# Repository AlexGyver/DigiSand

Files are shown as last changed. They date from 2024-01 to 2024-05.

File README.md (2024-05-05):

# DigiSand v1.3
 Цифровые песочные часы на Arduino
 
 Страница проекта: https://kit.alexgyver.ru/tutorials/digisand/

## Папки репозитория

> **3dprint** - модели корпуса для печати

> **firmware** - код для Arduino

> **libraries** - бибилиотеки (можно установить через IDE)

> **schemes** - схемы подключения

> **test** - модели песка для тестирования алгоритмов

## Для подключения звука

1. Добавить пищалку или мини-динамик (желательно с усилителем на транзисторе) на PIN D9
2. Раскомментируйте `#define BUZZER_PIN 9`
3. В настройках часов выберите одну из мелодий и/или отрегулируйте громкость

## Управление часами

- нажатие первой кнопки - уменьшить время на 1 сек
- нажатие и удержание первой кнопки - уменьшить время на 10 сек
- нажатие второй кнопки - увеличить время на 1 сек
- нажатие и удержание второй кнопки - увеличить время на 10 сек
- нажатие двух кнопок - сброс таймера
- удержание двух кнопок - вход в меню
- переход между пунктами меню - удержание одной из кнопок

Меню цикличное. Сверху - иконка пункта, снизу - значение.
Меню помнит последний использозванный пункт в течении 30 сек.
Меню выключается через 5 сек бездействия.

# Энергопотребление
- *при максимальной яркости* - **200мА**
- *при яркости 2* - **60мА**, во время проигрывания звука до 72мА
- *при минимальной яркости* - **35мА**, во время проигрывания звука до 45мА

# TODO
- добавить событие окончания времени, а не остановки песка
- Добавить анимации при окончании времени.
  Варианты:
  - мигание песка (вкл/выкл)
  - плавное мигание песка (плавное изменение яркости)
  - мигание пройденного времени
  - мультипликация (змейка, узор, шашечки, и т.п.)
- спящий режим (отключать экраны и лишние обработчики, уходит в сон, просыпаться по прерыванию от датчика наклона)
- добавить полноценную регулировку громкости, например на базе решения https://github.com/connornishijima/arduino-volume3

# Changelog

- v1.3 - добавлен контроль заряда при включении
- v1.2 - добавлен звук и 4 мелодии
- v1.1 - добавлено меню с иконками
- v1.0 - первая версия

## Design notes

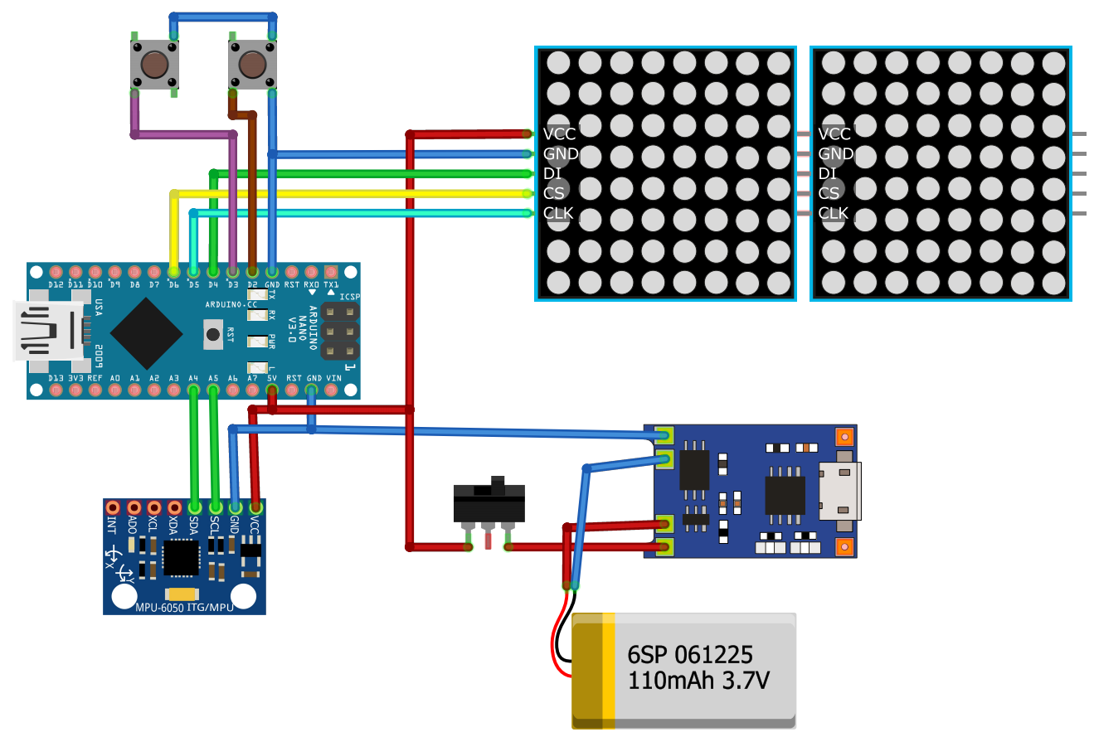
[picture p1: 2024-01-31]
schemes/scheme2.png

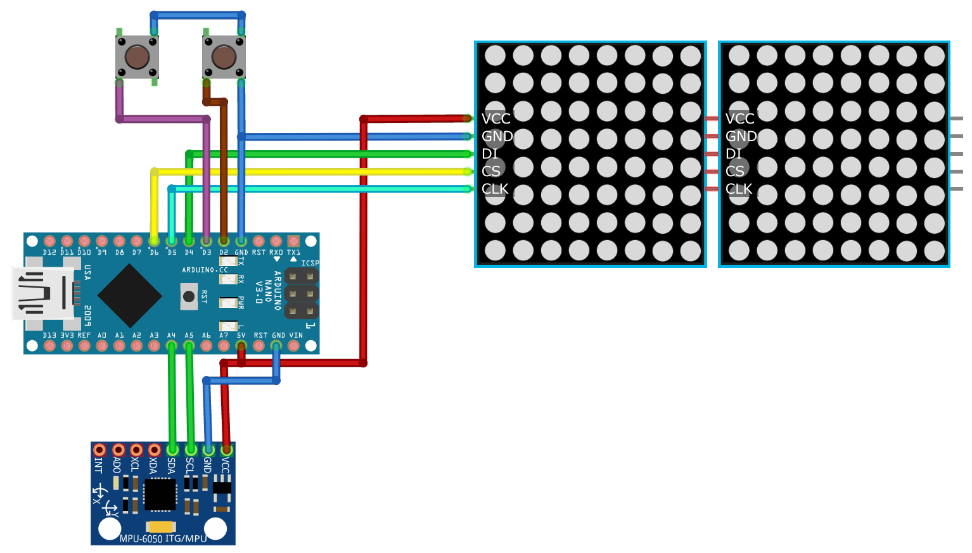
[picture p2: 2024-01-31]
schemes/scheme1.png

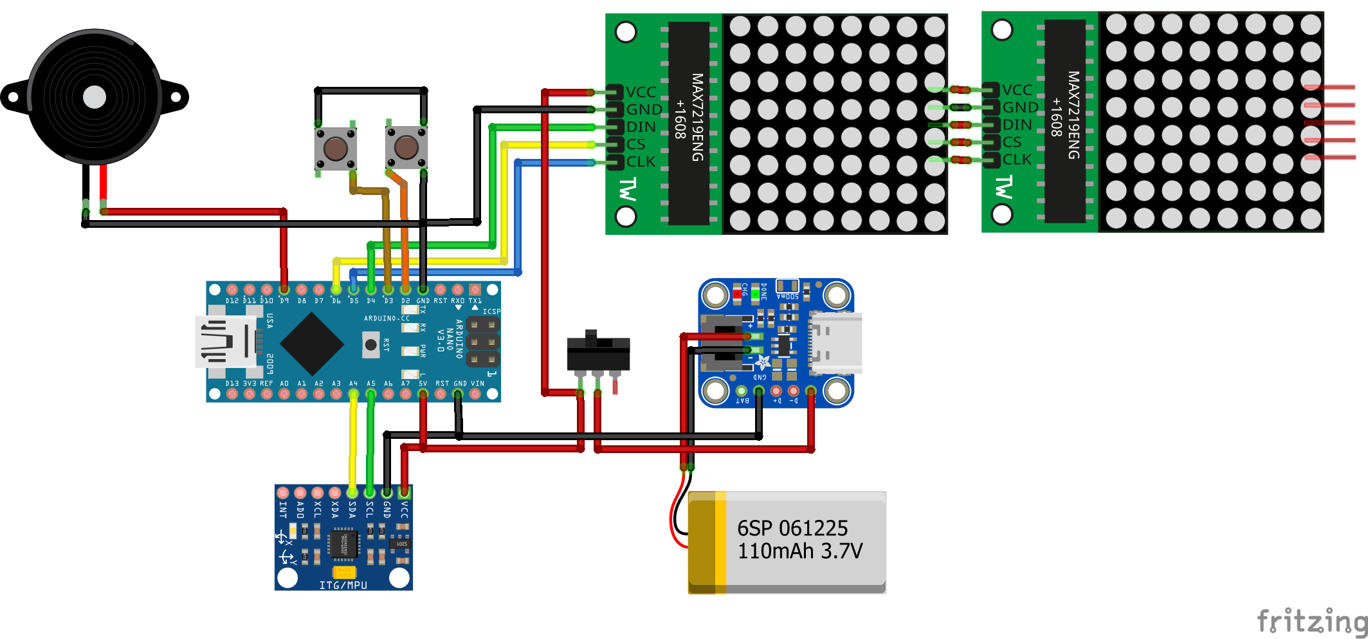
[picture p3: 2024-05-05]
schemes/scheme2_with_sound.png

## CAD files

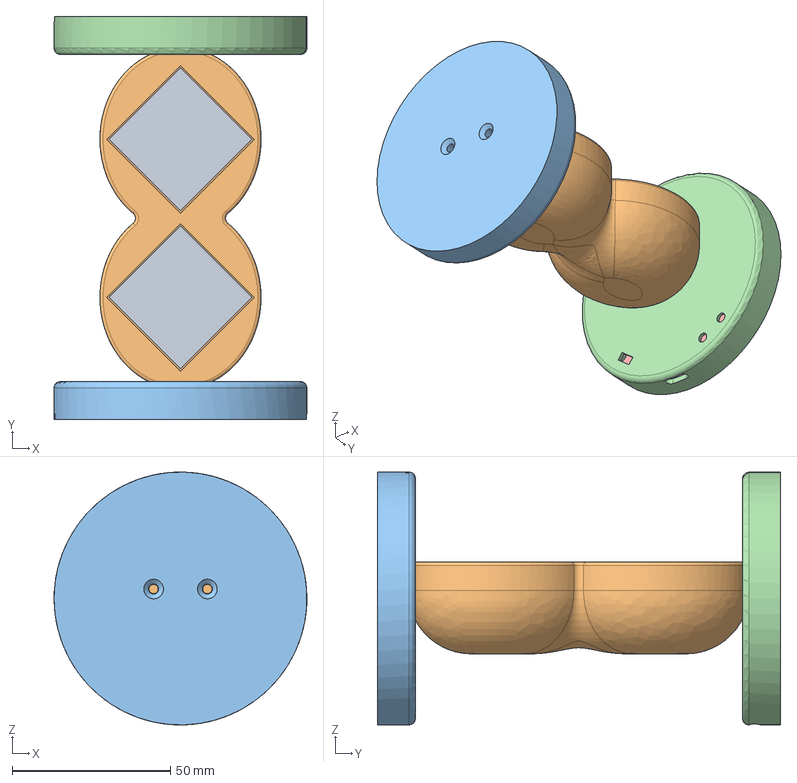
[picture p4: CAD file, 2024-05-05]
3dprint/clock v27.step
80.0 x 127.5 x 80.0 mm
matrix x 2
glass
bottom
top
cap

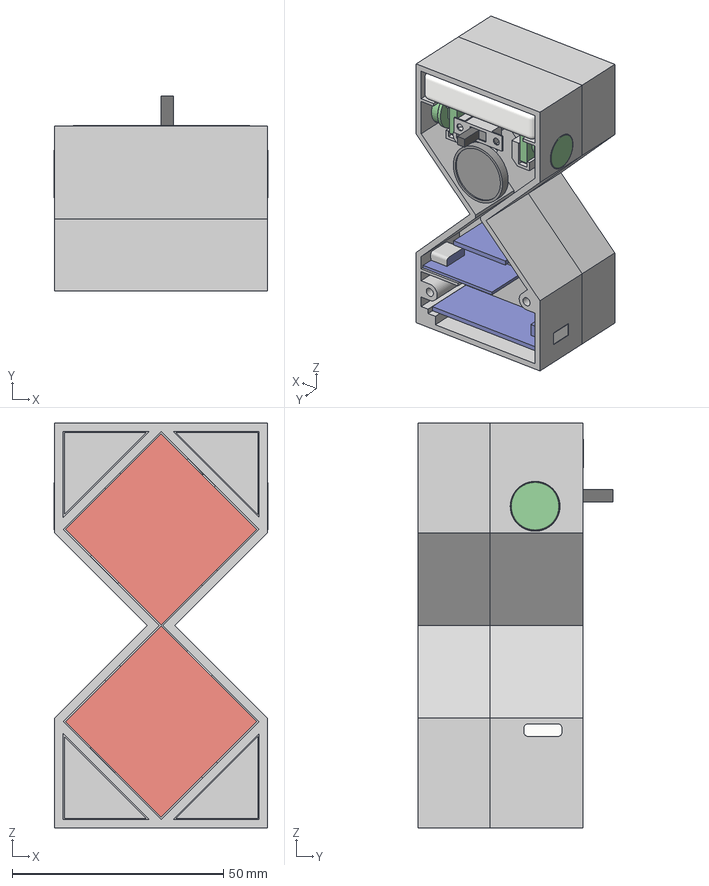
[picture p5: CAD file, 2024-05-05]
3dprint/digi-sand v2.3mf
50.6 x 46.1 x 95.9 mm
back
front
matrix1
matrix2

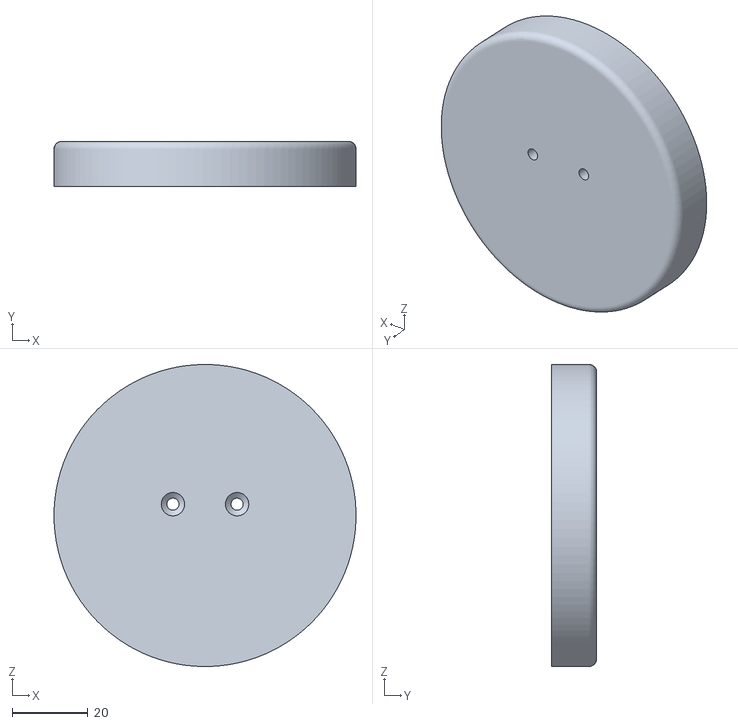
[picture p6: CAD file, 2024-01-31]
3dprint/bottom.stl
80.0 x 12.0 x 80.0

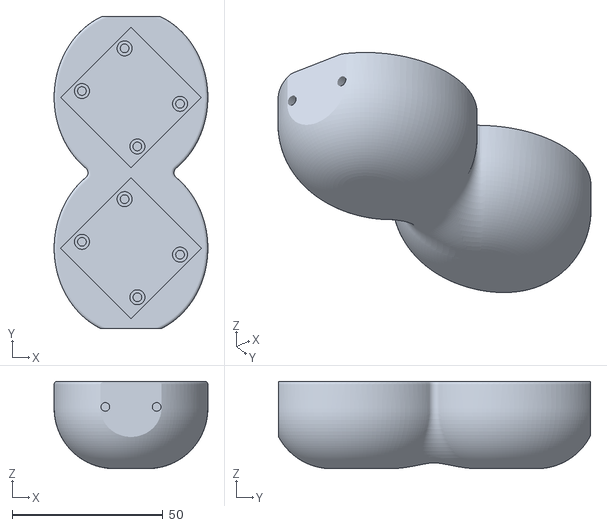
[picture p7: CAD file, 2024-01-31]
3dprint/glass.stl
51.0 x 103.5 x 29.0

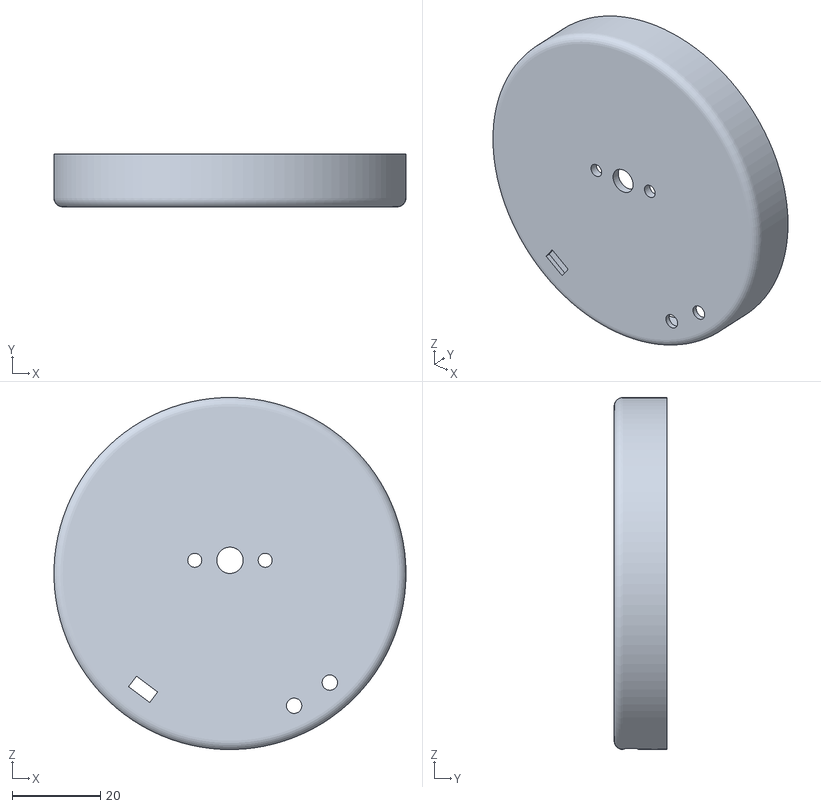
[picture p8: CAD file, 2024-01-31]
3dprint/top.stl
80.0 x 12.0 x 80.0

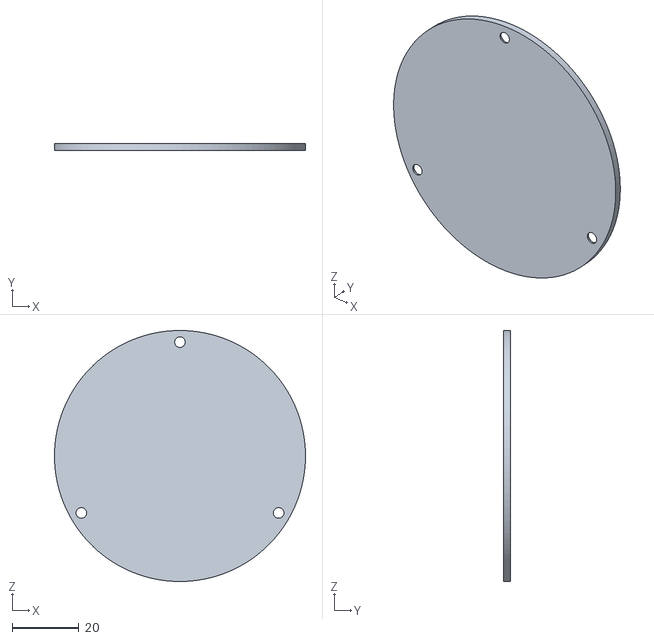
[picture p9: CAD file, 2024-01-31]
3dprint/cap.stl
75.5 x 2.00 x 75.5

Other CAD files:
3dprint/clock v27.f3d
3dprint/digi-sand v12.f3d

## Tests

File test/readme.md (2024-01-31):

## Test
Dev версии алгоритмов песка и частиц

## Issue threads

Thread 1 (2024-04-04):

Звук окончания отсчета.

Gomerchik, 2024-04-04:
Здравствуйте Алекс. Во-первых Спасибо Вам за Ваши труды. Я сам программировать не умею, но собрал несколько Ваших проектов) Вот и часики собрал тоже (и даже получилось на про мини), нужная вещь для настольных игр! Но как и говорили другие в комментах очень хотелось бы организовать звуковой сигнал с последней падающей песчинкой) Это конечно не совсем проблема, но за большим столом не всем видно часы, а звук был бы очень кстати. Может быть у Вас нашлось свободное время добавить данную  функцию в скетч?
В любом случае еще раз спасибо, творческих успехов...

nixprosoft, 2024-04-10:
> звук был бы очень кстати.

Добавил звук в PR https://github.com/AlexGyver/DigiSand/pull/2

Gomerchik, 2024-04-23:
Доброго дня.
Премного благодарен за проделанную работу!!!
Наконец-то дошли руки сделать апгрейт. Часики зажили новой жизнью)) 
 
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
Добавил звук в PR  #2
—
Reply to this email directly,  view it on GitHub , or  unsubscribe .
You are receiving this because you authored the thread. Message ID:  <AlexGyver/DigiSand/issues/1/2047565510 @ github . com>  
 
С уважением,
Станислав Миронов
***@***.***
 

Gomerchik, 2024-04-23:
Еще раз здрасти.
Скажите пожалуйста а вы можете отредактировать начало воспроизведения звука окончания? Чтобы он сразу начинался с падением последней песчинки? А не как сейчас спустя время между падениями. На небольшом временном отрезке это не заметно, но если часы стоят хотя бы на 5 минут, то последняя песчинка падает, а звук начинается спустя не сколько секунд. И чем дольше время, тем больше задержка.
Спасибо.
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
Добавил звук в PR  #2
—
Reply to this email directly,  view it on GitHub , or  unsubscribe .
You are receiving this because you authored the thread. Message ID:  <AlexGyver/DigiSand/issues/1/2047565510 @ github . com>  
 
С уважением,
Станислав Миронов
***@***.***
 

nixprosoft, 2024-05-05:
> последняя песчинка падает, а звук начинается спустя не сколько секунд

Здравствуйте. Не обращали внимания, пока Вы не сказали. В бытовых целях это не так критично. Нужно подумать. Получается, что звук окончания начинается с опозданием? Проверяли секундомером?

Gomerchik, 2024-05-06:
Здравствуйте.
Да, проверял, Это очень заметно на большом времени.
Звук начинается не с момента падения последней песчинки, а с момента, когда должна упасть следующая. Чем больше время, тем больше задержка между песчинками и следовательно задержка в мелодии.
Спасибо.
 
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
Здравствуйте. Не обращали внимания, пока Вы не сказали. В бытовых целях это не так критично. Нужно подумать. Получается, что звук окончания начинается с опозданием? Проверяли секундомером?
—
Reply to this email directly,  view it on GitHub , or  unsubscribe .
You are receiving this because you authored the thread. Message ID:  <AlexGyver/DigiSand/issues/1/2094975986 @ github . com>  
 
С уважением,
Станислав Миронов
***@***.***
 

nixprosoft, 2024-05-09:
@Gomerchik Вы правы. Это связано с логикой работы программы. Идёт ожидание очередной песчинки, и если она не проскочила, то играет музыка. Подсчёт песчинок не ведётся. Создайте новый issue, пожалуйста.

GyverLibs, 2024-05-09:
Так и знал что кому то не понравится :)

Gomerchik, 2024-05-09:
Кому тут, что не нравится?;)
Лично мне все нравится!

nixprosoft, 2024-05-09:
То самое чувство, когда накотил :)
Я думаю, что можно подсчитывать число песчинок в обеих емкостях. Общее число мы знаем, направления проталкивания знаем, попробую реализовать.

nixprosoft, 2024-05-09:
@Gomerchik Решил Вашу проблему https://github.com/AlexGyver/DigiSand/pull/3
@GyverLibs накотил подсчёт, теперь работает корректно.

Gomerchik, 2024-06-25:
Доброго времени суток. Наконец-то дошли руки залить новую прошивку. Спасибо. Вот только почему-то теперь сбился таймер( Ставлю минуту а в реале часы отсчитывают всего 30 секунд. Ставлю две минуты - часы отсчитывают минуту((

nixprosoft, 2024-07-10:
> Доброго времени суток. Наконец-то дошли руки залить новую прошивку. Спасибо. Вот только почему-то теперь сбился таймер( Ставлю минуту а в реале часы отсчитывают всего 30 секунд. Ставлю две минуты - часы отсчитывают минуту((

Опишите, как это повторить, пожалуйста. Не наблюдаю указанных проблем на своём экземпляре.

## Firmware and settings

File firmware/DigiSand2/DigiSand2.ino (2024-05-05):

#include <Arduino.h>

#include "print3x5.h"

#define PART_AMOUNT 58  // общее число песчинок на поле
#define BTN1_PIN 2
#define BTN2_PIN 3
#define CS_PIN 6
#define DT_PIN 4
#define CK_PIN 5
#define SOUND_PIN 9

#define MaxVolume 1  // максимальный уровень громкости эффектов
#define MaxMelody 5  // число имеющихся мелодий (для корректной работы меню)

#define battery_min 3000  // минимальный уровень заряда батареи для отображения 3000
#define battery_max 3800  // максимальный уровень заряда батареи для отображения  3800

// Структура конфигурации для хранения в EEPROM
struct Data {
  int16_t sec = 60;  // время
  int8_t bri = 2;    // яркость
  int8_t vol = 1;    // громкость эффектов
  int8_t mel = 1;    // мелодия окончания времени
  int8_t ani = 0;    // анимации окончания времени
  int8_t tmpo = 4;   // темп проигрывания мелодий
  int8_t bat = 1;
};
Data data;

#include <EEManager.h>
EEManager memory(data);

// button
#include <EncButton.h>
Button up(BTN1_PIN);
Button down(BTN2_PIN);
VirtButton dbl;

// matrix
#include <GyverMAX7219.h>
MAX7219<2, 1, CS_PIN, DT_PIN, CK_PIN> mtrx;

// mpu
#include "mini6050.h"
Mini6050 mpu;

// sandbox
#define BOX_W 16
#define BOX_H 16

#include "sand.h"
Sand<BOX_W, BOX_H> box;

// timer
#include "Timer.h"
Timer fall_tmr, disp_tmr, menu_tmr;

// ============== ВАШ КОД ==============
// функция вызывается при каждом "проталкивании" песчинки
void onSandPush() {
#ifdef SOUND_PIN
  StopMelody();  // чтобы мелодия не накладывалась на звук падающего песка
  if (data.vol > 0) PlaySandPushTone();
#endif
}

// todo
//    сложность в том, что событие onSandEnd должно срабатывать именно тогда, когда весь песок пересыпался
//    с учётом возможных пауз из-за наклонов
//    возможно, тут получится сделать таймер, который будет отсчитывать настроенные секунды, делать паузу когда нужно и автоматом обнуляться, когда весь песок пересыпется
//    либо нужно отследить число частиц на втором экране
// функция вызывается при завершении времени отведённого времени
// void onSandEnd() {

// }

// функция вызывается, когда песок перестал сыпаться
// это происходит в том числе из-за крена часов, когда ещё не весь песок пересыпался
void onSandStop() {
#ifdef SOUND_PIN
  if (data.mel > 0) PlayMelody(data.mel);
#endif
}

// функция вызывается, когда заряд батареи ниже порога
void onBatteryEmpty() {
  mtrx.setBright(0);
  while (true) {
    mtrx.clear();
    printIcon(&mtrx, 0, 0, 6);
    mtrx.update();
    delay(1000);
    mtrx.clear();
    printIcon(&mtrx, 0, 0, 4);
    mtrx.update();
    delay(1000);
  }
}

uint8_t inMenu = 0;
uint8_t lastUsedMenu = 0;    // последнее использованное меню
unsigned long voltage;       // напряжение аккумулятора
float my_vcc_const = 1.080;  // константа вольтметра

// =====================================

bool runFlag = 1;
bool checkBound(int8_t x, int8_t y) {
  if (y >= 8 && x < 8) return 0;
  if (y < 8 && x >= 8) return 0;
  if (mpu.getDir() > 0) {
    if (x == 8 && y == 8) return 0;
  } else {
    if (x == 7 && y == 7) return 0;
  }
  return (x >= 0 && y >= 0 && x < BOX_W && y < BOX_H);
}
void setXY(int8_t x, int8_t y, bool value) {
  if (y >= 8) y -= 8;
  mtrx.dot(x, y, value);
}

void resetSand() {
  box.buf.clear();
  mtrx.clear();
  mtrx.update();
  for (uint8_t n = 0; n < PART_AMOUNT; n++) {
    box.buf.set(n % 8, n / 8, 1);
  }
}

void setup() {
  //Serial.begin(115200);
  Wire.begin();
  mpu.begin();
  memory.begin(0, 'a');
  mtrx.begin();
  mtrx.setBright(data.bri);

  mpu.setX({ 1, -1 });
  mpu.setY({ 2, 1 });
  mpu.setZ({ 0, 1 });

  box.attachBound(checkBound);
  box.attachSet(setXY);

#ifdef SOUND_PIN
  pinMode(SOUND_PIN, OUTPUT);
  SetTempo(data.tmpo);
#endif

  voltage = readVcc();  // считать напряжение питания
  // Serial.println(voltage);
  if (voltage <= battery_min) onBatteryEmpty();
  showBattLevel(voltage);
  delay(2000);  // время отображения заряда после включения

  resetSand();
  fall_tmr.setInterval(data.sec * 1000ul / PART_AMOUNT);
}

void changeTime(int8_t dir) {
  disp_tmr.setTimeout(3000);
  mtrx.clear();
  data.sec += dir;
  if (data.sec < 0) data.sec = 0;
  uint8_t min = data.sec / 60;
  uint8_t sec = data.sec % 60;

  printDig(&mtrx, 0, 1, min / 10);
  printDig(&mtrx, 4, 1, min % 10);
  printDig(&mtrx, 8 + 0, 1, sec / 10);
  printDig(&mtrx, 8 + 4, 1, sec % 10);

  fall_tmr.setInterval(data.sec * 1000ul / PART_AMOUNT);
  memory.update();
  mtrx.update();
}

// изменение темпа
void changeTempo(int8_t dir) {
  data.tmpo += dir;
  data.tmpo = constrain(data.tmpo, 1, 7);
  SetTempo(data.tmpo);
  PlayMelody(data.mel);
  memory.update();
}

// изменение анимации
void changeAni(int8_t dir) {
  data.ani += dir;
  data.ani = constrain(data.ani, 0, 1);
  memory.update();
}

// изменение яркости
void changeBri(int8_t dir) {
  data.bri += dir;
  data.bri = constrain(data.bri, 0, 15);
  mtrx.setBright(data.bri);
  memory.update();
}

// изменение громкости
void changeVol(int8_t dir) {
  data.vol += dir;
  data.vol = constrain(data.vol, 0, MaxVolume);
  memory.update();
}

// изменение мелодии
void changeMel(int8_t dir) {
  data.mel += dir;
  data.mel = constrain(data.mel, 0, MaxMelody);
  if (data.mel) PlayMelody(data.mel);
  else StopMelody();
  memory.update();
}

// изменение стиля отображения заряда
void changeBat(int8_t dir) {
  data.bat += dir;
  data.bat = constrain(data.bat, 0, 2);
  memory.update();
}

void enterMenu(int8_t menu) {
  disp_tmr.setTimeout(returnFromMenu, 5000);
  mtrx.clear();

  // здесь настраивается число доступных пунктов меню
  if (menu > 5) menu = 1;
  if (menu < 1) menu = 5;

  inMenu = menu;
  menu_tmr.setTimeout(forgetLastMenu, 30000);

  showMenu(menu);
}

void forgetLastMenu() {
  lastUsedMenu = 0;
}

void showMenu(int8_t menu) {
  // выводим иконку меню на первый экран
  // и текущее значение параметра на втворой
  switch (menu) {
    case 1:  // яркость
      printIcon(&mtrx, 0, 0, 2);
      printDig(&mtrx, 8 + 0, 1, data.bri / 10);
      printDig(&mtrx, 8 + 4, 1, data.bri % 10);
      break;

    case 2:  // громкость звуков
      printIcon(&mtrx, 0, 0, 0);
      printDig(&mtrx, 8 + 0, 1, data.vol / 10);
      printDig(&mtrx, 8 + 4, 1, data.vol % 10);
      break;

    case 3:  // мелодия окончания
      printIcon(&mtrx, 0, 0, 1);
      printDig(&mtrx, 8 + 0, 1, data.mel / 10);
      printDig(&mtrx, 8 + 4, 1, data.mel % 10);
      break;

    case 4:  // темп мелодий
      printIcon(&mtrx, 0, 0, 5);
      printDig(&mtrx, 8 + 0, 1, data.tmpo / 10);
      printDig(&mtrx, 8 + 4, 1, data.tmpo % 10);
      break;

    case 5:  // стиль отображения заряда при включении
      printIcon(&mtrx, 0, 0, 6);
      printDig(&mtrx, 8 + 0, 1, data.bat / 10);
      printDig(&mtrx, 8 + 4, 1, data.bat % 10);
      break;

    case 6:  // анимации
      printIcon(&mtrx, 0, 0, 3);
      printDig(&mtrx, 8 + 0, 1, data.ani / 10);
      printDig(&mtrx, 8 + 4, 1, data.ani % 10);
      break;
  }
  mtrx.update();
}

// Отображение уровня заряда в процентах или вольтах
void showBattLevel(long voltage) {
  int8_t level = 0;
  switch (data.bat) {
    case 1:
      level = map(voltage, battery_min, battery_max, 0, 99);
      level = constrain(level, 0, 99);
      mtrx.clear();
      printIcon(&mtrx, 0, 0, 4);
      printDig(&mtrx, 8 + 0, 1, level / 10);
      printDig(&mtrx, 8 + 4, 1, level % 10);
      mtrx.update();
      break;
    case 2:
      mtrx.clear();
      printDig(&mtrx, 0, 1, voltage / 1000);
      printDig(&mtrx, 4, 1, (voltage % 1000) / 100);
      printDig(&mtrx, 8 + 0, 1, (voltage % 100) / 10);
      printDig(&mtrx, 8 + 4, 1, (voltage % 100) % 10);
      mtrx.update();
      delay(2000);
      mtrx.clear();
      break;
  }
}

void changeMenuParam(int8_t menu, int8_t val) {
  disp_tmr.setTimeout(returnFromMenu, 5000);  // обновляем таймер
  mtrx.clear();                               // очищаем экран

  switch (menu) {
    case 1:            // яркость
      changeBri(val);  // сохраняем новое значение яркости
      break;
    case 2:  // громкость звуков
      changeVol(val);
      break;
    case 3:  // мелодия окончания
      changeMel(val);
      break;

    case 4:              // темп мелодий
      changeTempo(val);  // сохраняем новое значение темпа
      break;

    case 5:  // отображение заряда
      changeBat(val);
      break;

    case 6:  // анимация окончания
      changeAni(val);
      // todo
      // Варианты:
      // - мигание песка (вкл/выкл)
      // - плавное мигание песка (игра с яркостью)
      break;
  }
  showMenu(menu);
}

// колбэк для выхода из меню по таймауту
void returnFromMenu() {
  lastUsedMenu = inMenu;  // запоминаем последнее использованное
  inMenu = 0;
}

// обработчик кнопок
void buttons() {
  up.tick();
  down.tick();
  dbl.tick(up, down);

  if (!inMenu) {
    if (dbl.hold()) enterMenu(lastUsedMenu ? lastUsedMenu : 1);
    if (dbl.click()) resetSand();

    // останавливаем проигрывание мелодии при нажатии на любую кнопку
    if (up.click()) isMelodyPlaying() ? StopMelody() : changeTime(1);
    if (up.step()) changeTime(10);
    if (up.hold()) changeTime(10);

    // останавливаем проигрывание мелодии при нажатии на любую кнопку
    if (down.click()) isMelodyPlaying() ? StopMelody() : changeTime(-1);
    if (down.step()) changeTime(-10);
    if (down.hold()) changeTime(-10);
  } else {
    if (dbl.click()) returnFromMenu();
    if (up.hold()) enterMenu(inMenu + 1);
    if (down.hold()) enterMenu(inMenu - 1);
    if (up.click()) changeMenuParam(inMenu, 1);
    if (down.click()) changeMenuParam(inMenu, -1);
  }
}

void step() {
  uint16_t prd = 255 - mpu.getMag();
  prd = constrain(prd, 15, 90);
  if (mpu.update(prd)) {
    mtrx.clear();
    box.step(mpu.getAngle() + 45);
    mtrx.update();
  }
}

void fall() {
  if (fall_tmr) {
    bool pushed = 0;
    if (mpu.getDir() > 0) {
      if (box.buf.get(7, 7) && !box.buf.get(8, 8)) {
        box.buf.set(7, 7, 0);
        box.buf.set(8, 8, 1);
        box.setCallback(7, 7, 0);
        box.setCallback(8, 8, 1);
        pushed = 1;
      }
    } else {
      if (box.buf.get(8, 8) && !box.buf.get(7, 7)) {
        box.buf.set(8, 8, 0);
        box.buf.set(7, 7, 1);
        box.setCallback(8, 8, 0);
        box.setCallback(7, 7, 1);
        pushed = 1;
      }
    }

    if (pushed) {
      runFlag = 0;
      mtrx.update();
      onSandPush();
    } else {
      if (!runFlag) {
        runFlag = 1;
        onSandStop();
      }
    }
  }
}

// Главный цикл
void loop() {
  memory.tick();
  disp_tmr.tick();
#ifdef SOUND_PIN
  soundsTick();
#endif
  buttons();

  if (!disp_tmr.state()) {
    step();
    fall();
  }
}

unsigned long readVcc() {  //функция чтения внутреннего опорного напряжения, универсальная (для всех ардуин)
#if defined(__AVR_ATmega32U4__) || defined(__AVR_ATmega1280__) || defined(__AVR_ATmega2560__)
  ADMUX = _BV(REFS0) | _BV(MUX4) | _BV(MUX3) | _BV(MUX2) | _BV(MUX1);
#elif defined(__AVR_ATtiny24__) || defined(__AVR_ATtiny44__) || defined(__AVR_ATtiny84__)
  ADMUX = _BV(MUX5) | _BV(MUX0);
#elif defined(__AVR_ATtiny25__) || defined(__AVR_ATtiny45__) || defined(__AVR_ATtiny85__)
  ADMUX = _BV(MUX3) | _BV(MUX2);
#else
  ADMUX = _BV(REFS0) | _BV(MUX3) | _BV(MUX2) | _BV(MUX1);
#endif
  delay(2);             // Wait for Vref to settle
  ADCSRA |= _BV(ADSC);  // Start conversion
  while (bit_is_set(ADCSRA, ADSC))
    ;                   // measuring
  uint8_t low = ADCL;   // must read ADCL first - it then locks ADCH
  uint8_t high = ADCH;  // unlocks both
  long result = (high << 8) | low;
  result = my_vcc_const * 1023 * 1000 / result;  // расчёт реального VCC
  return result;                                 // возвращает VCC
}

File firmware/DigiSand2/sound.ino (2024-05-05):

#include "pitches.h"

// V trave sidel kuznechik - 1 - FIXED
const uint16_t melody1[][2] PROGMEM = {
      {NOTE_A4, 300},	{ NOTE_E4, 150},	{0, 150}, { NOTE_A4, 300},	{ NOTE_E4, 150},{0, 150}, { NOTE_A4, 300},	{ NOTE_GS4, 150},	{0, 150}, { NOTE_GS4, 300},	{0, 300},	
      {NOTE_GS4, 300},{ NOTE_E4, 150},	{0, 150}, { NOTE_GS4, 300},	{ NOTE_E4, 150},{0, 150}, { NOTE_GS4, 150},	{0, 150}, { NOTE_A4, 150},	{0, 150}, { NOTE_A4, 300},	{0, 300},	
      {NOTE_A4, 300},	{ NOTE_E4, 150},	{0, 150}, { NOTE_A4, 300},	{ NOTE_E4, 150},{0, 150}, { NOTE_A4, 300},	{ NOTE_GS4, 150},	{0, 150}, { NOTE_GS4, 300},	{0, 300},	
      {NOTE_GS4, 300},{ NOTE_E4, 150},	{0, 150}, { NOTE_GS4, 300},	{ NOTE_E4, 150},{0, 150}, { NOTE_GS4, 150},	{0, 150}, { NOTE_A4, 750}, {0, 150},	
      {NOTE_A4, 300},	{NOTE_B4, 150},	{0, 150}, {NOTE_B4, 140}, {0, 10},	{NOTE_B4, 140}, {0, 10},	{NOTE_B4, 150}, {0, 150},	
      {NOTE_B4, 300},	{NOTE_C5, 150},	{0, 150}, {NOTE_C5, 140}, {0, 10},	{NOTE_C5, 140}, {0, 10},	{NOTE_C5, 150}, {0, 150},
      {NOTE_C5, 150},	{0, 150}, {NOTE_C5, 300},	{NOTE_B4, 150},	{0, 150}, {NOTE_A4, 300},	{NOTE_GS4, 150}, {0, 150}, {NOTE_A4, 150}, {0, 150}, {NOTE_A4, 300},	{0, 300},	
      {NOTE_A4, 300},	{NOTE_B4, 150},	{0, 150}, {NOTE_B4, 140}, {0, 10},	{NOTE_B4, 140}, {0, 10},	{NOTE_B4, 150}, {0, 150},	
      {NOTE_B4, 300},	{NOTE_C5, 150},	{0, 150}, {NOTE_C5, 140}, {0, 10},	{NOTE_C5, 140}, {0, 10},	{NOTE_C5, 150}, {0, 150},
      {NOTE_C5, 150},	{0, 150}, {NOTE_C5, 300},	{NOTE_B4, 150},	{0, 150}, {NOTE_A4, 300},	{NOTE_GS4, 150}, {0, 150}, {NOTE_A4, 600},	
};

// Crazy Frog - 2 - FIXED
const uint16_t melody2[][2] PROGMEM = {
      {NOTE_D4, 450},	{0, 150},	{NOTE_F4, 300},	{0, 150}, {NOTE_D4, 150},	{0, 150},	{NOTE_D4, 150},	{NOTE_G4, 150},	{0, 150}, {NOTE_D4, 150}, {0, 150}, {NOTE_C4, 150},	{0, 150},
      {NOTE_D4, 450},	{0, 150},	{NOTE_A4, 300},	{0, 150}, {NOTE_D4, 150},	{0, 150},	{NOTE_D4, 150},	{NOTE_AS4, 150}, {0, 150}, {NOTE_A4, 150}, {0, 150}, {NOTE_F4, 150}, {0, 150}, 	
      {NOTE_D4, 300},	{NOTE_A4, 150},	{0, 150}, {NOTE_D5, 150}, {0, 150}, {NOTE_D4, 150},	{NOTE_C4, 150},	{0, 150},	{NOTE_C4, 150},	{NOTE_A3, 150},	{0, 150}, {NOTE_E4, 300},	{NOTE_D4, 450}
};

// Mario - 3
const uint16_t melody3[][2] PROGMEM = {
{NOTE_E6, 50}, {0, 50}, 	{ NOTE_E6, 100}, {0, 100}, 	{ NOTE_E6, 50}, {0, 100}, 	{ NOTE_C6, 50}, {0, 50}, 	{ NOTE_E6, 100}, {0, 100}, 	{ NOTE_G6, 200}, {0, 200}, 	
{ NOTE_G5, 200}, {0, 200}, 	{NOTE_C6, 150}, {0, 150}, 	{ NOTE_G5, 50}, {0, 150}, 	{ NOTE_E5, 100}, {0, 150}, 	{ NOTE_A5, 100}, {0, 100}, 	{ NOTE_B5, 50}, {0, 100}, 	
{ NOTE_AS5, 50}, {0, 50}, 	{ NOTE_A5, 100}, {0, 100}, 	{ NOTE_G5, 70}, {0, 70}, 	{NOTE_E6, 70}, {0, 70}, 	{ NOTE_G6, 50}, {0, 50}, 	{ NOTE_A6, 100}, {0, 100}, 	
{ NOTE_F6, 50}, {0, 50}, 	{ NOTE_G6, 50}, {0, 100}, 	{ NOTE_E6, 100}, {0, 100}, 	{ NOTE_F6, 50}, {0, 50}, 	{ NOTE_D6, 50}, {0, 50}, 	{ NOTE_B5, 150}, {0, 150}, 
{NOTE_C6, 150}, {0, 150}, 	{ NOTE_G5, 50}, {0, 150}, 	{ NOTE_E5, 100}, {0, 150}, 	{ NOTE_A5, 100}, {0, 100}, 	{ NOTE_B5, 50}, {0, 100}, 	{ NOTE_AS5, 50}, {0, 50}, 	
{ NOTE_A5, 100}, {0, 100}, 	{NOTE_G5, 70}, {0, 70}, 	{ NOTE_E6, 70}, {0, 70}, 	{ NOTE_G6, 50}, {0, 50}, 	{ NOTE_A6, 100}, {0, 100}, 	{ NOTE_F6, 50}, {0, 50}, 	
{ NOTE_G6, 50}, {0, 100}, 	{ NOTE_E6, 100}, {0, 100}, 	{ NOTE_C6, 50}, {0, 50}, 	{ NOTE_D6, 50}, {0, 50}, 	{ NOTE_B5, 150}, {0, 200}, 	{NOTE_G6, 50}, {0, 50}, 	
{ NOTE_FS6, 50}, {0, 50}, 	{ NOTE_F6, 50}, {0, 50}, 	{ NOTE_DS6, 100}, {0, 100}, 	{ NOTE_E6, 50}, {0, 100}, 	{ NOTE_GS5, 50}, {0, 50}, 	{ NOTE_A5, 50}, {0, 50}, 	
{ NOTE_C6, 50}, {0, 100}, 	{ NOTE_A5, 50}, {0, 50}, 	{ NOTE_C6, 50}, {0, 50}, 	{ NOTE_D6, 50}, {0, 50}, 	{0, 0}, {0, 100}, 	{ NOTE_G6, 50}, {0, 50}, 	{ NOTE_FS6, 50}, {0, 50}, 	
{ NOTE_F6, 50}, {0, 50}, 	{ NOTE_DS6, 100}, {0, 100}, 	{ NOTE_E6, 50}, {0, 100}, 	{ NOTE_C7, 100}, {0, 100}, 	{ NOTE_C7, 50}, {0, 50}, 	{ NOTE_C7, 200}, {0, 200}, 	{NOTE_G6, 50}, {0, 50}, 	
{ NOTE_FS6, 50}, {0, 50}, 	{ NOTE_F6, 50}, {0, 50}, 	{ NOTE_DS6, 100}, {0, 100}, 	{ NOTE_E6, 50}, {0, 100}, 	{ NOTE_GS5, 50}, {0, 50}, 	{ NOTE_A5, 50}, {0, 50}, 	{ NOTE_C6, 50}, {0, 100}, 	
{ NOTE_A5, 50}, {0, 50}, 	{ NOTE_C6, 50}, {0, 50}, 	{ NOTE_D6, 50}, {0, 150}, 	{ NOTE_DS6, 100}, {0, 150}, 	{ NOTE_D6, 150}, {0, 150}, 	{ NOTE_C6, 200}, {0, 400}
};

// Beb bep - 4
const uint16_t melody4[][2] PROGMEM = {
  {NOTE_B7, 40}, {0, 40}, {NOTE_B7, 40}, {0, 40}, {NOTE_B7, 40}, {0, 40}, {NOTE_B7, 40}, {0, 40},
  {0, 200},
  {NOTE_B7, 40}, {0, 40}, {NOTE_B7, 40}, {0, 40}, {NOTE_B7, 40}, {0, 40}, {NOTE_B7, 40}, {0, 40},
  {0, 200},
  {NOTE_B7, 40}, {0, 40}, {NOTE_B7, 40}, {0, 40}, {NOTE_B7, 40}, {0, 40}, {NOTE_B7, 40}, {0, 40},
  {0, 200},
  {NOTE_B7, 40}, {0, 40}, {NOTE_B7, 40}, {0, 40}, {NOTE_B7, 40}, {0, 40}, {NOTE_B7, 40}, {0, 40},
  {0, 200},
  {NOTE_B7, 40}, {0, 40}, {NOTE_B7, 40}, {0, 40}, {NOTE_B7, 40}, {0, 40}, {NOTE_B7, 40}, {0, 40},
};

// Ka by nebylo zimy - 5
const uint16_t melody5[][2] PROGMEM = {
  {NOTE_B3,200}, {NOTE_B3,200}, {NOTE_B4,300}, {NOTE_FS4,100},
  {NOTE_A4,200}, {NOTE_G4,200}, {NOTE_E4,400}, {0,25},
  {NOTE_D4,200}, {NOTE_D4,200}, {NOTE_D5,300}, {NOTE_C5,100}, {NOTE_C5,200},{NOTE_B4,200},{0,400},
  {NOTE_D5,200},{NOTE_C5,200}, {NOTE_A4,200},{NOTE_FS4,200}, {NOTE_C5,200},{NOTE_B4,200},{NOTE_B4,400},
  {NOTE_B3,200}, {NOTE_B3,200}, {NOTE_B4,300}, {NOTE_A4,100},{NOTE_A4,200}, {NOTE_G4,200}, {0,400},
  {NOTE_B3,200}, {NOTE_B3,200}, {NOTE_B4,300}, {NOTE_FS4,100},
  {NOTE_A4,200}, {NOTE_G4,200}, {NOTE_E4,400}, {PAUZA,25},
  {NOTE_D4,200}, {NOTE_D4,200}, {NOTE_D5,300}, {NOTE_C5,100}, {NOTE_C5,200},{NOTE_B4,200},{PAUZA,200},
  {NOTE_E5,400},{NOTE_C5,200}, {NOTE_A4,200}, {NOTE_FS4,200}, {NOTE_C5,200},{NOTE_B4,200},{NOTE_B4,400},{PAUZA,25},
  {NOTE_B3,200}, {NOTE_B3,200}, {NOTE_B4,300}, {NOTE_A4,100},{NOTE_A4,200}, {NOTE_G4,200}, {PAUZA,200},
  {NOTE_E5,400},{NOTE_C5,200}, {NOTE_A4,200}, {NOTE_FS4,200}, {NOTE_C5,200},{NOTE_B4,200},{NOTE_B4,400},{PAUZA,25},
  {NOTE_B3,200}, {NOTE_B3,200}, {NOTE_B4,300}, {NOTE_DS4,100},{NOTE_FS4,200}, {NOTE_E4,200}, {PAUZA,400}
};

// tick - 10
const uint16_t sound1[][2] PROGMEM = {
  {NOTE_B5, 10}, {NOTE_B7, 10}
};
const uint16_t sound2[][2] PROGMEM = {
  {NOTE_B0, 20}
};

unsigned long toneMillis;
uint8_t tonePlaying = 0;

unsigned long melodyMillis;
uint8_t melodyPlaying = 0;
uint16_t melodyStep = 0;
size_t melodySize = 0;
float melodyTempo = 1;
const float tempos[7] PROGMEM = { 1.4, 1.2, 1.1, 1, 0.9, 0.75, 0.6 };
const uint8_t melodyOctave = 1; // октава воспроизведения мелодий (лучше не трогать)

void SetTempo(uint8_t val) {
  melodyTempo = pgm_read_float(&tempos[val - 1]);
}

void soundsTick() {
  if(melodyPlaying && (millis() > melodyMillis)) {
    if(melodyStep < melodySize - 1) {
      melodyStep++;
      RunMelodyNote();
    } else {
      StopMelody();
    }
  }
}

bool isMelodyPlaying() {
  return melodyPlaying > 0;
}
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

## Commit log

2024-04-10 v1.3 со звуком, и меню с иконками
    [clock v27.step, digi-sand v12.f3d, digi-sand v2.3mf]
2024-04-10 Добавил сведения об энергопотреблении
2024-04-17 Отрегулировал верхний порог для аккумулятора 3.7В, Исправил ноты первых двух мелодий
    [scheme2_with_sound.fzz]
2024-04-18 Добавил в меню управление отображением заряда. При запуске на разряженной батарее будет отображаться мигающая батарейка. Скорректировал управление темпом мелодий
